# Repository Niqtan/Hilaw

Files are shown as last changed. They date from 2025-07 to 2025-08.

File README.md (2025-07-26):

# Hilaw (3D Printed Instant Camera)

## Project Aims

Hilaw, in english, Raw, is a hybrid analog & digital camera used for taking personal pictures in order to preserve memories. 

Before snapping a picture, a sample image will pop up in the TFT display, having a preview unlike traditional polaroid cameras. Then, using an Arducam module as the camera sensor, it is able to capture images with of high quality.

Afterwards, logic is sent to the thermal printer to print that picture instantly. In the long term, using a thermal printer with sticker paper (I want to be able to stick my memories), will be very cost-effective than traditional film paper, albeit only white and black colors will be in the picture when printing.

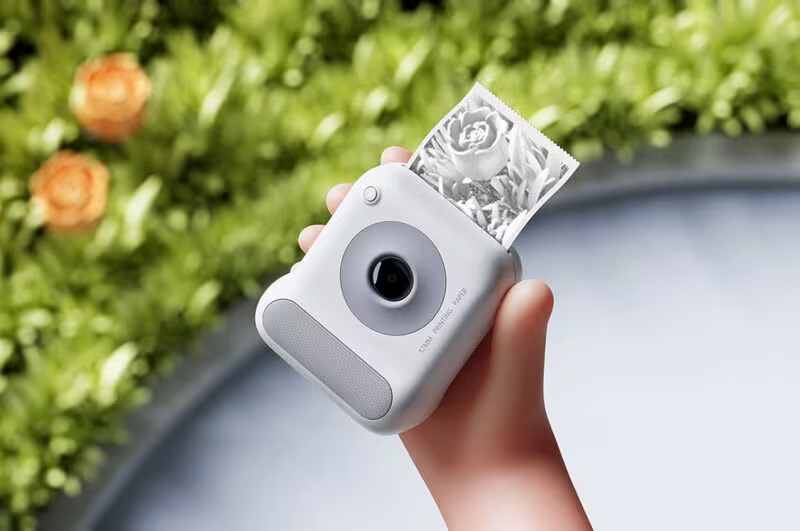
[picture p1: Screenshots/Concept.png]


Image 1. Concept of the project
Courtesy of [TrendHunter](https://www.trendhunter.com/trends/thermal-print-camera)

## Power Management PCB
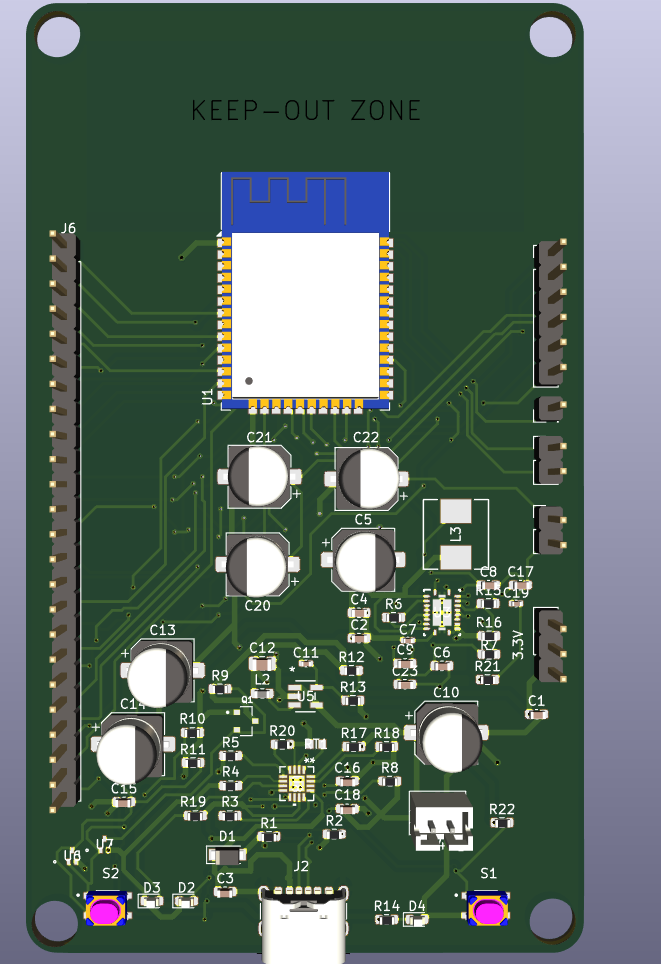
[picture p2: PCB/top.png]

Image 2. Top view of PCB

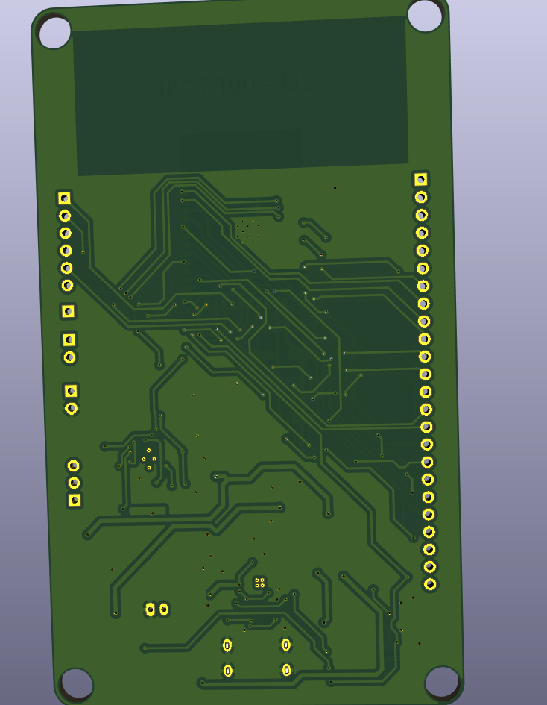
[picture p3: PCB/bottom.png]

Image 3. Bottom view of PCB

## Layout & Schematic
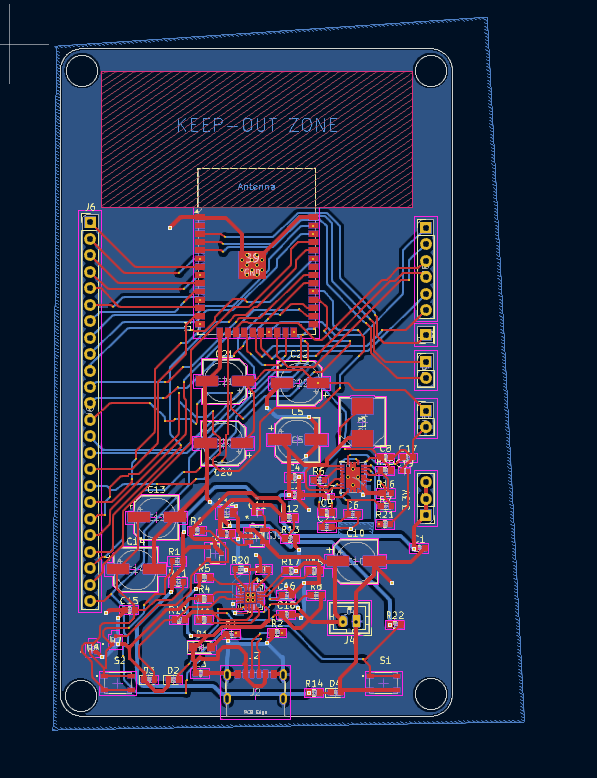
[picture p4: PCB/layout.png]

Image 4. PCB Layout & Connections 

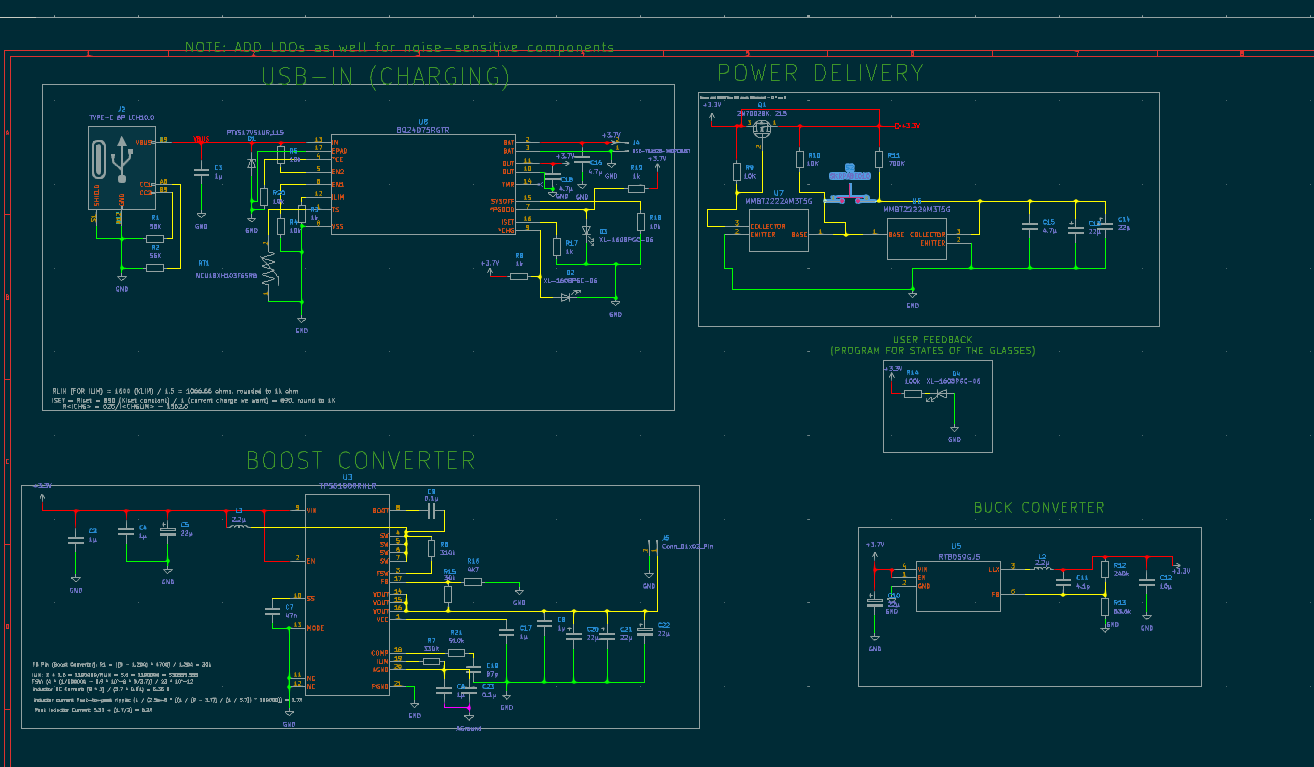
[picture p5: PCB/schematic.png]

Image 5. Power Schematic of the PCB

P.S. The PCB was mainly used for creating a power management module just for this. The rest are pretty much built-in modules to buy.

## CAD
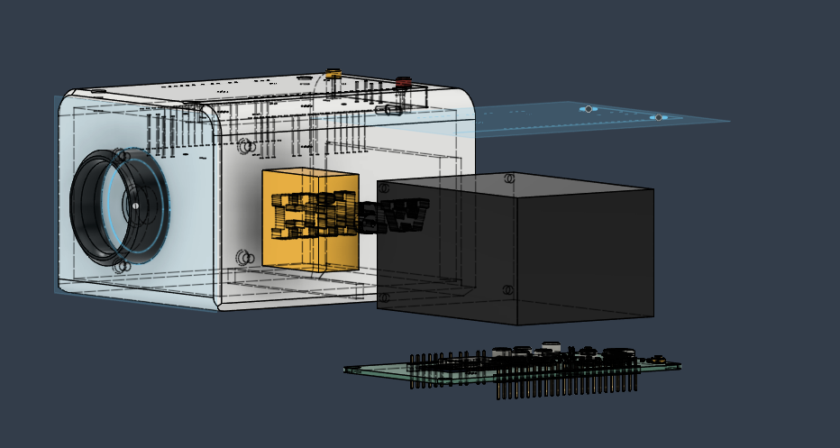
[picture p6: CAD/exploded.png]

Image 6. Exploded View of the CAD

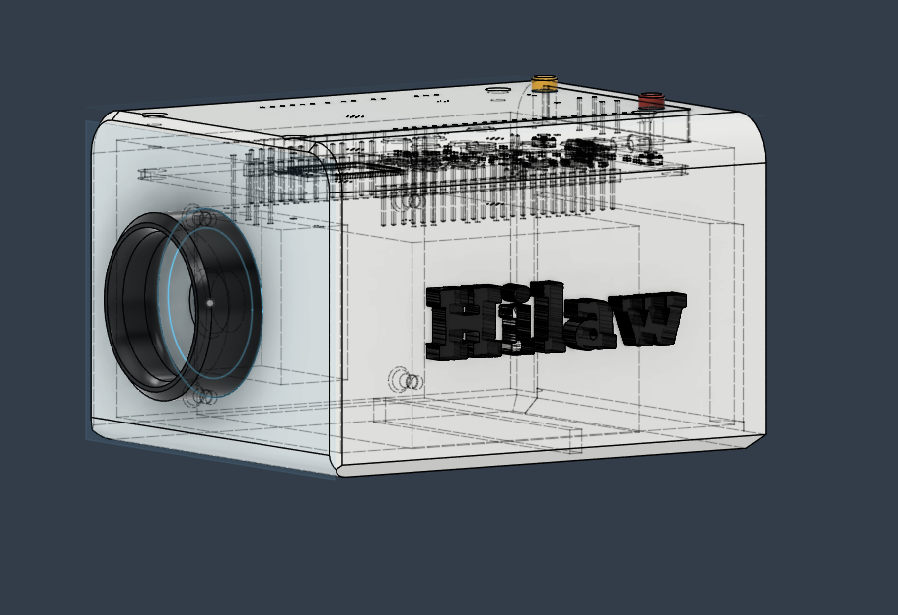
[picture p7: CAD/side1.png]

Image 7. Side View of the CAD

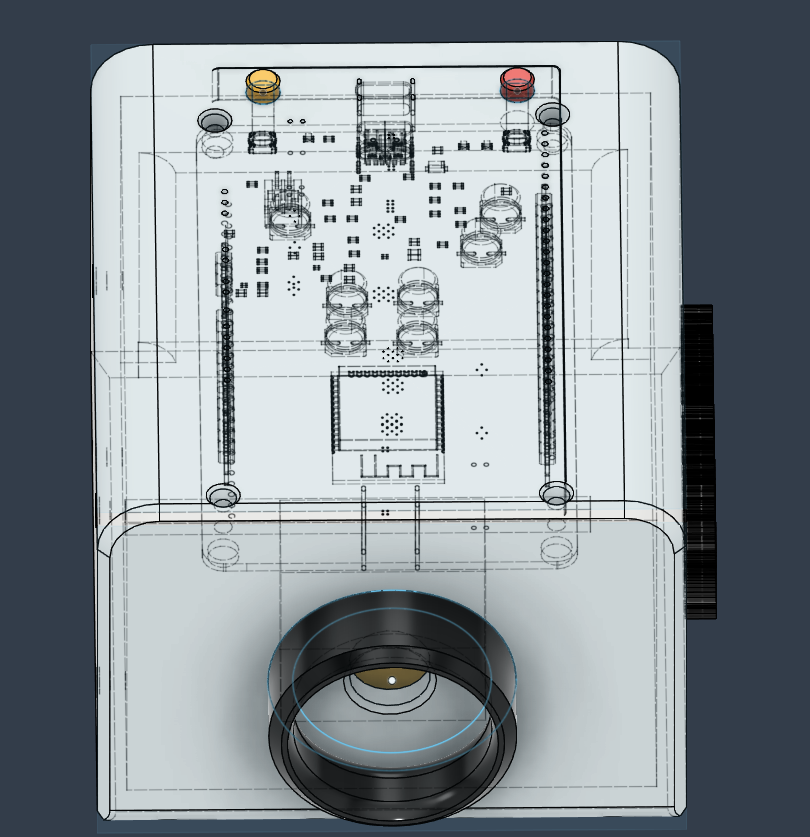
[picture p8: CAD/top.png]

Image 8. Top view of the CAD

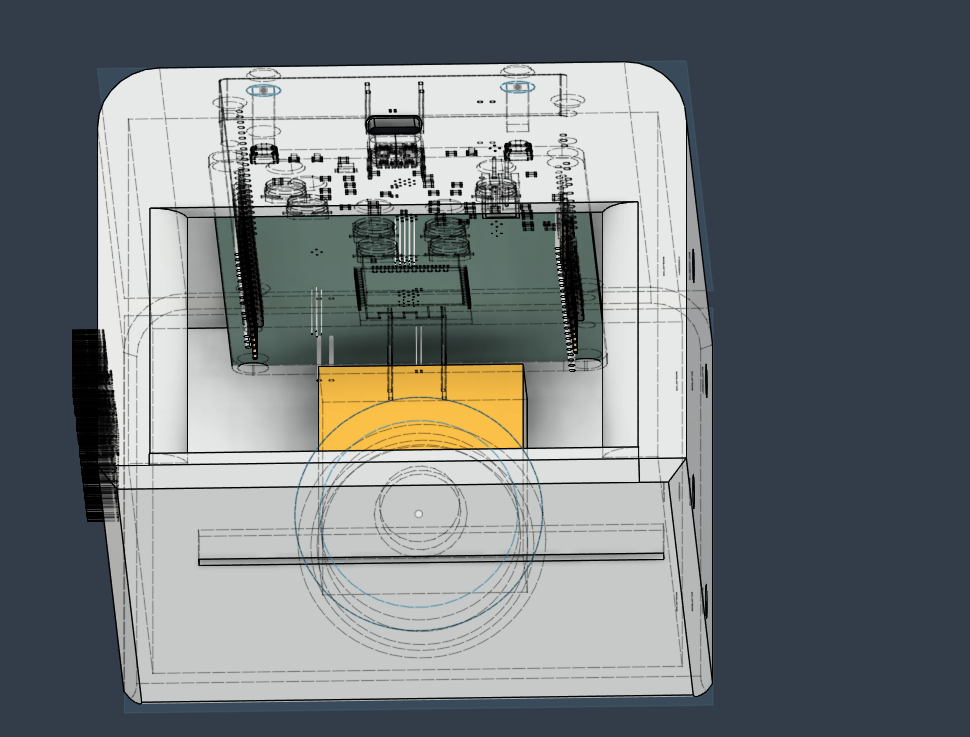
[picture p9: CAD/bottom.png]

Image 9. Bottom View of the CAD

## 3D Printing
In terms of 3D Printing this project, I will print this in Resin since some of these are curved (also the lens cutout is circular). You may print this in Resin with the following parameters:

Layer height: 0.05mm

Orientation: 30-45 degrees

thats pretty much it 

## BOM
[View the bom](BOM.csv)

## Firmware
Have not yet started on the firmware. I am going to choose the Arduino IDE in order to program the ESP32-WROOM-32 since it is much more convenient for prototyping.

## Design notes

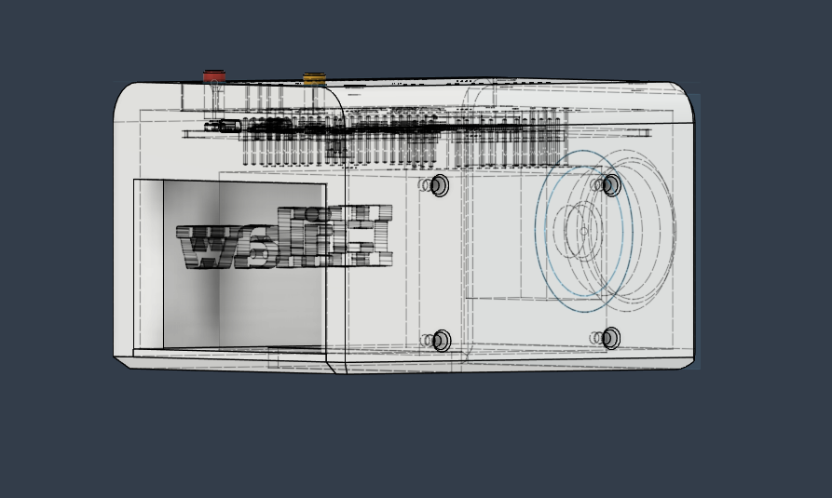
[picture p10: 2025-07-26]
CAD/side2.png

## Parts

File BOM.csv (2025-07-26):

Comment | Designator | Footprint | LCSC Part # | Total (USD)
1µ Unpolarized capacitor | C1,C2,C3,C4,C6,C8,C17 | C_0603_1608Metric | C1592 | IN PCBA
22µ Polarized capacitor | C5,C10,C13,C14,C20,C21,C22 | CP_Elec_6.3x5.4 | C7469954 | IN PCBA
47n Unpolarized capacitor | C7 | C_0402_1005Metric | C1525 | IN PCBA
0.1µ Unpolarized capacitor | C9,C23 | C_0603_1608Metric | C1590 | IN PCBA
4.1p Unpolarized capacitor | C11 | C_0402_1005Metric | C1525 | IN PCBA
10µ Unpolarized capacitor | C12 | C_0805_2012Metric | C1713 | IN PCBA
4.7μ Unpolarized capacitor | C15,C16,C18 | C_0603_1608Metric | C1705 | IN PCBA
87p Unpolarized capacitor | C19 | C_0402_1005Metric | C1525 | IN PCBA
PTVS17VS1UR,115 Zener diode | D1 | Nexperia_CFP3_SOD-123W | C396100 | IN PCBA
XL-1608PGC-06 Light emitting diode | D2,D3,D4 | LED_0603_1608Metric | C7371905 | IN PCBA
USB_C_Receptacle_GCT_USB4125-xx-x-0190_6P_TopMnt_Horizontal | J2 | TYPE-C 6P LCH10.0 USB Power-Only 6P Type-C Receptacle connector | C5187470 | IN PCBA
USE-702528-500PCBJST Generic connector, single row, 01x02, script generated | J4 | JST_PH_B2B-PH-K_1x02_P2.00mm_Vertical | C5251182 | IN PCBA
Conn_01x24_Pin Generic connector, single row, 01x24, script generated | J6 | PinHeader_1x24_P2.54mm_Vertical | C7430380 | IN PCBA
Conn_01x03_Pin Generic connector, single row, 01x03, script generated | J7 | PinHeader_1x03_P2.54mm_Vertical | C49257 | IN PCBA
Conn_01x06_Pin Generic connector, single row, 01x06, script generated | J8 | PinHeader_1x06_P2.54mm_Vertical | C37208 | IN PCBA
Conn_01x01_Pin Generic connector, single row, 01x01, script generated | J10 | PinHeader_1x01_P2.54mm_Vertical | C81276 | IN PCBA
2.2µ Inductor | L2 | L_0603_1608Metric | C1033 | IN PCBA
2.2µ Inductor | L3 | IND_FXL0630_CMT | C167211 | IN PCBA
2N7002BK, 215 0.2A Id, 200V Vds, N-Channel MOSFET, 2.6V Logic Level, TO-92 | Q1 | TRANS_PMV130ENEAR | C458143 | IN PCBA
56K Resistora | R1,R2 | R_0603_1608Metric | C23206 | IN PCBA
1k Resistor | R3,R8,R17,R19 | R_0603_1608Metric | C11702 | IN PCBA
10k Resistor | R4,R5,R18,R20,R22 | R_0603_1608Metric | C25804 | IN PCBA
310k Resistor | R6 | R_0603_1608Metric | C23137 | IN PCBA
330K Resistor | R7 | R_0603_1608Metric | C23137 | IN PCBA
10K Resistor | R9,R10 | R_0603_1608Metric | C25804 | IN PCBA
700K Resistor | R11 | R_0603_1608Metric | C25606 | IN PCBA
240k Resistor | R12 | R_0603_1608Metric | C4197 | IN PCBA
53.6k Resistor | R13 | R_0603_1608Metric | C23074 | IN PCBA
100k Resistor | R14 | R_0603_1608Metric | C25803 | IN PCBA
30k Resistor | R15 | R_0603_1608Metric | C18681 | IN PCBA
4k7 Resistor | R16 | R_0603_1608Metric | C100444 | IN PCBA
910k Resistor | R21 | R_0603_1608Metric | C23263 | IN PCBA
NCU18XH103F6SRB | RT1 | TRES_NCU18XH103F6SRB_MUR | C162670 | IN PCBA
SKRPABE010 | S1,S2 | SW_SKRPABE010 | C115360 | IN PCBA
ESP32-WROOM-32 RF Module, ESP32-D0WDQ6 SoC, Wi-Fi 802.11b/g/n, Bluetooth, BLE, 32-bit, 2.7-3.6V, onboard antenna, SMD | U1 | ESP32-WROOM-32 | C82899 | IN PCBA
TPS61088RHLR | U3 | RHL0020A | C87357 | IN PCBA
RT8059GJ5 | U5 | TSOT-23-5_RIT | C20542 | IN PCBA
MMBT2222AM3T5G | U6,U7 | SOT-723_0P85X1P25_ONS-M | C896289 | IN PCBA
BQ24075RGTR | U8 | RGT16_1P7X1P7 | C15464 | IN PCBA
NOT IN PCB |  |  |  | IN PCBA
ARDUCAM (B0401) | N/A | N/A | N/A | $53.66
GOOJPRT QR204 Thermal Printer | N/A | N/A | N/A | $20.18
TFT_320x240 ( provided) | N/A | N/A | N/A | $0
Shipping & Etc
Aliexpress Thermal Printer |  |  |  | $16.87
PCBA Assembly |  |  |  | $102.55
PCB & PCBA Shipping |  |  |  | $11.72
 |  |  |  | $204.98

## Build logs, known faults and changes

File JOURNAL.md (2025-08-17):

---
title: "Hilaw"
author: "Niq Suguitan"
description: "Holy shit I hate running out of storage ~ probably me" 
created_at: "2025-07-08"
---

| Date started: July 7, 2025

Total hours spent: 57 hours

# Entry #0 - 07-07-25

Research on the components

So for this entry, I've been mainly just going around scouting components
in digikey.

Here are some obsidian notes:

Project Making - Building your own Instax Camera - 07-05-25

Project Name: Hilaw

Features:
- OLED screen preview (Hybrid between digital and analog)
	- Allow users to choose when to print it
- Press a button -> take a pictures
- Adjust settings
- Storage (SD Card)
- Processing on a thermal printer
- Power
	- Latching circuit
	- USB-C w SD CARD

Parts needed:
- ArduCAM
- TFT LCD
- Thermal Printer
- MCU (ESP BOARD SERIES)
	- ESP-32-S3
- Power system

Components - Camera Module - 07-07-25

Characteristics
- Megapixels
	- Megapixels are usually a metric for cropping
	- Basically, if you crop something, it will still retain its quality 

What makes a better image quality?
- Attributed to lower noise
- Better colours
- Dynamic Range

Great camera modules:
- ESP32-CAM

The good thing about ESP32-CAM:
- Cost-effective
- Doesn't take too much dev time
- Fits right perfectly
- Option to be coded with the ESP board series

Cons of ESP32-CAM:
- Video streaming wasnt the best
	- The resolution wasnt the best

Comparing this with the Raspberry Pi Cam V2
- RP
	- Image quality - much better due to SONY sensor
	- 8 MP

Why is the ESP32-CAM stitll much better?
- Its compact and wireless
- Not that complex for this project

For this project, I would pick a camera that is:
- Plug and play, fast *development*
- Has the bare minimum
- Doesn't have to have manual image control

Ends there

Total hours spent: 5 hours

# Entry #1 - 07-19-25 - Researching more components

You guessed it! More research!

What is thermal printing?
- Imagine the receipts, thermal printing is used to print those

By using the same principle of thermal printers, we can:
- Print instantly using heat

Cons of thermal printing
- They start to fade away
- Depends on paper

Thermal Printer vs Inkjet
- Inkjet
	- Paper jam
- Thermal Printers
	- Embedded Thermal Printer V2.0

Components - LCD vs OLED Screen - 07-07-25

Feature focused on: Preview of the camera's printed image

What is OLED?
- Display technology that exhibits amazing contrast since the pixels turn off to display black
- Composed of organic material that emits light when an electric current is applied

LCD
- Utilizes a backlight that shines through liquid crystals to create an image
- Control the amount of light that passes through, dictating the color and brightness of pixels

Benchmarks

Contrast ratio and black levels
- OLED technology outshiens LCD when it comes to this
- Each pixel on the OLED screen is independently lit,

LCD
- On the other hand, LCDs, regardless of backlight technology used, always emit some level of light even when trying to display black, leading a lower contrast ratio

Lifespan and Burn-in
- LCD displays are not susceptible to these issues
- OLED
	- The organic materials in OLED dipslays can degrade over time
	- Moreover, if static images are displayed for extended periosd, OLED screens can suffer from burn-in
		- Where ghost images are permanently imprinted in the screens

Energy Efficiency
- Another area where LCDs tend to excel
	- Generally consume less power than OLEDs when displaying bright or white backgrounds
	- However, the same cannot be said when dark or black images are on the screen as OLEDs consume less power 

Conclusion: 
- We're gonna use a TFT LCD
	- Difference between a TFT LCD and a normal one is that its much more robust (TFT LCD) due to new technology

Total hours spent: 5 hours

# Entry #2 - 07-22-25 - Researching Power Electronics & Doing the Schematic

For this entry, I've started doing the schematic. I only focused on making this a power only PCB, and I focused the most on getting the power part to work so I can work with the PCB straight away.

Here is another peek of my obisdian note for power calculations:

ESP32-WROOM-32 Power Characteristics:
- Power supply voltage -> -0.3V - 3.6V (absolute max)
- Minimum power supply current -> >= 500mAh
- Probably 800mAh to accomodate for the other components

ILI9341 LCD Characteristics (TFT LCD)
- Supply voltage (Logic): 3.3V (Absolute maximum characteristic)
- Around 100mA

ARDUCAM (Camera sensor)
- Supply voltage: 3.3V to 5V
- Peak current (Working): 154mA

Thermal Printer (DF Robot Embedded printer)
- Working voltage: 9V
- Working current: 1.5A - 2A when printing

What to do:
- Since the thermal printer requires a lot more power than the other components, the power system's  requirements would have to be:
	- Battery capacity: 2Ah with discharge rate of 2C 
		  discharge rate is important because it dictates the rate of which it delivers electrical energy
		  That basically means the speed of which it discharges the current we need
		  So lets say we had a 1Ah battery but the charge is only 0.5C, well that would only deliver 500mA

Basic principle of boost converter:
- Boost converters do not boost current, they boost voltage at the expense of current
- Basic principle:
	- V in  * I in = V out * Iout

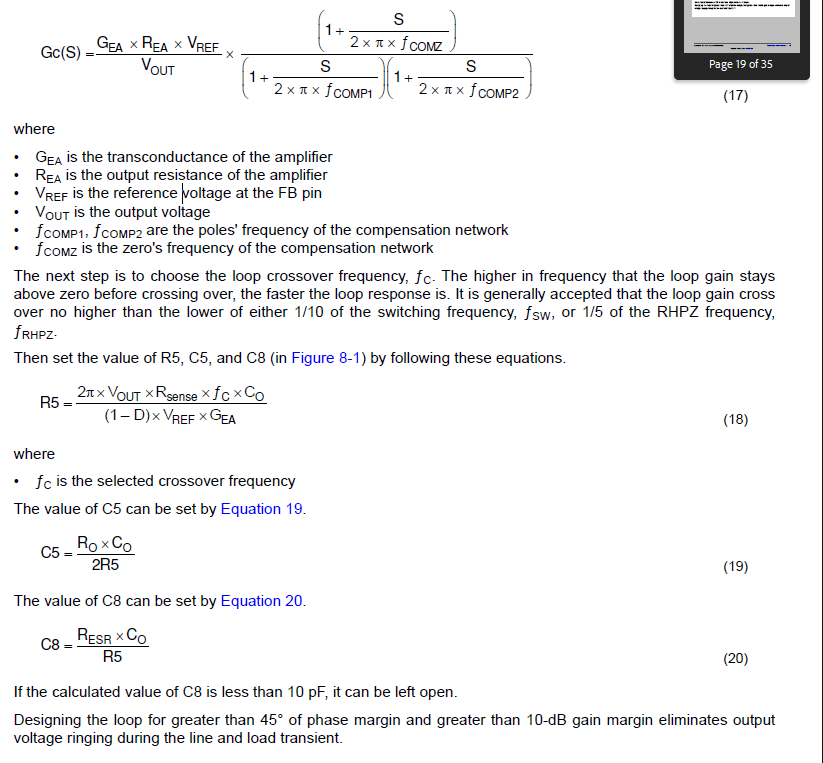
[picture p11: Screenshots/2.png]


Total hours spent: 6 hours

# Entry #4 - 07-24-25 - Finishing up the schematic for power management

In this journal, I mainly polished up the schematic. I've been reading a lot of datasheets and been scrolling thru a lot of them, just to make sure I don't  get anything wrong.

Here's the final schematic (Power management only since this PCB is for that)

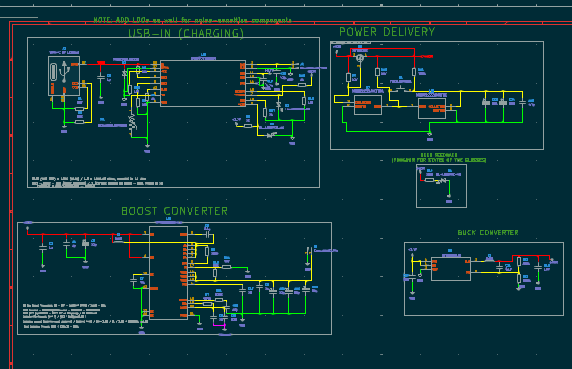
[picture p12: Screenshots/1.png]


Also, I've gotten a jumpstart at the PCB. Its been in the making currently. Didn't get any pictures sadly, forgot em.

Total hours spent: 6 hours

# Entry #5 - 07-25-25 - Finishing the PCB Layout for power management

In this entry, I have finished up the PCB layout. Here is how it looks:

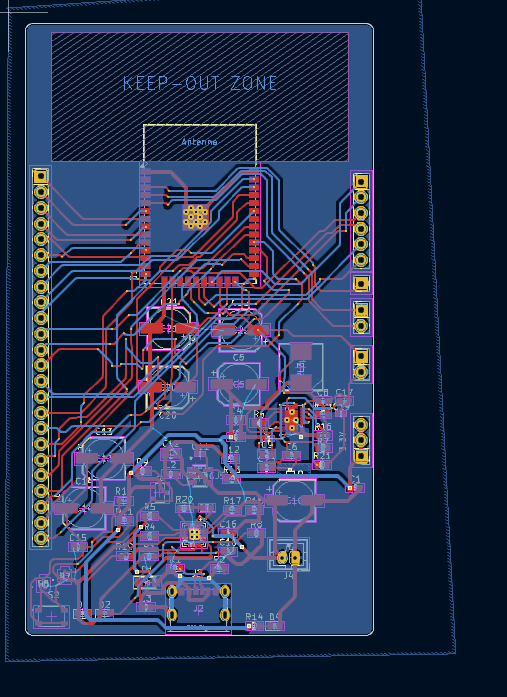
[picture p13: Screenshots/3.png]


Also, I've gotten a jumptart of the CAD. I've been mainly thinking about how to fit all of these components. For example, how would I fit the PCB, thermal printer, and Arducam inside it?

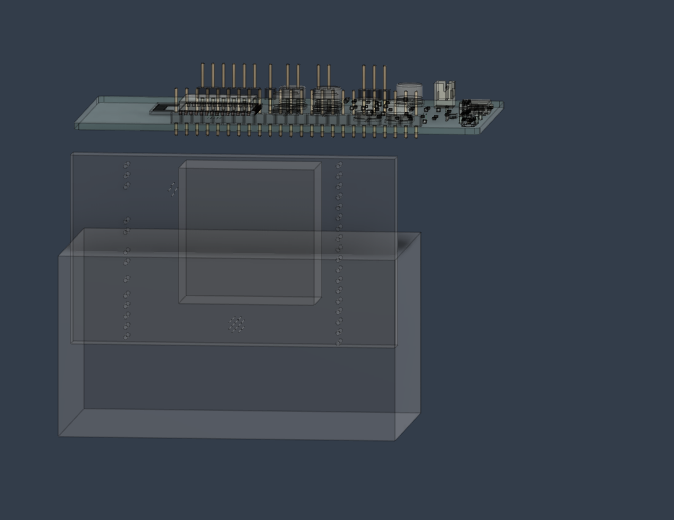
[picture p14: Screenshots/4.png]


Also, I've been brainstorming what the hell do I do with the buttons. I heard its great to have a square on top of the tactile switch with 0.5mm clearance. so I did that on top of the circular model of the button. I did that for both buttons! Power and shutter, which have self-explanatory usages for cameras.

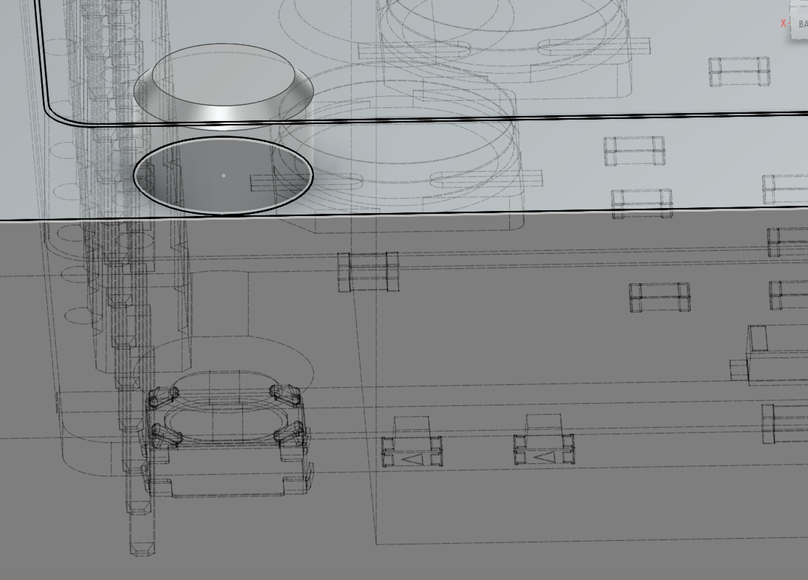
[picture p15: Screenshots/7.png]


Total hours spent: 8 hours

# Entry #6 - 07-26-25 - Finishing up the CAD 

I've been experimenting with how to mount the PCB so that it is stable throughout the usage of the PCB. I decided to go for screws with the standoffs so it doesnt fall on the ceiling of the CAD.

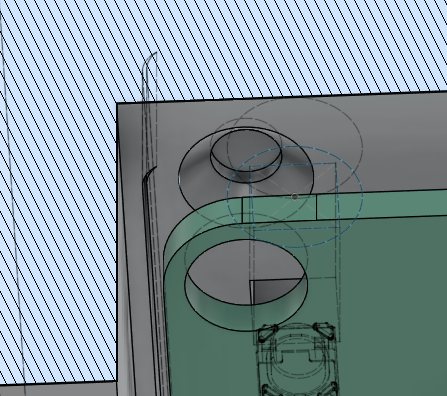
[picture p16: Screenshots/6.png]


Aaaandd... here is what the final CAD looks like! I decided to make this super simple. I didn't want it to be that designy, since I just wanted to use this

Here is what it looks like:


total hours spent: 6 hours

# Entry 7 - 07-29-25 - Ordering PCB & Other Stuff

For this entry, I've ordered most of what I need to assemble this!

- ✔️ PCB
- ✔️ Thermal Printer
- ✔️ Camera (albeit, differnet one since budget didn't reach)

See pictures:
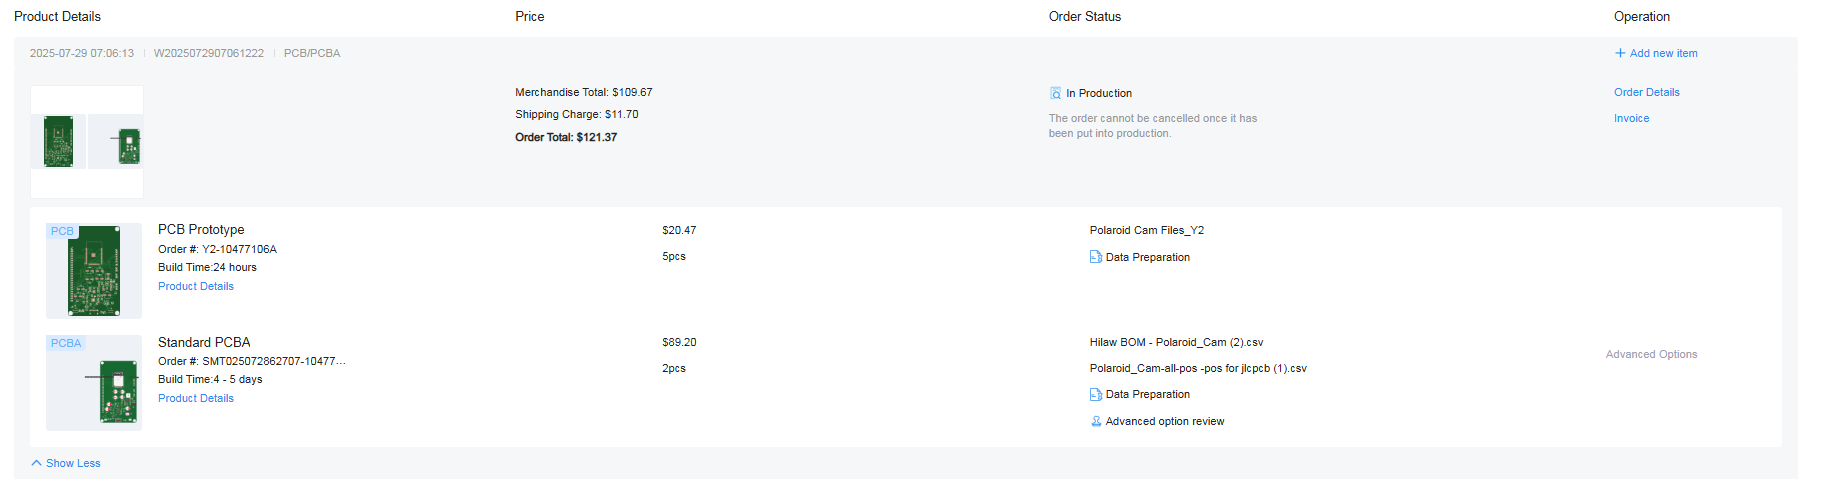
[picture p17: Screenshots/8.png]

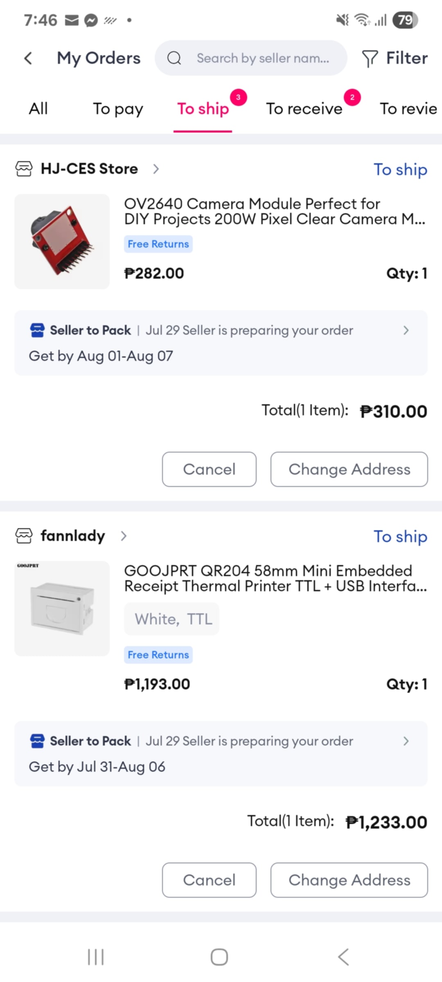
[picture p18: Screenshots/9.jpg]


Total hours spent: 1 hour

# Entry 8 -  07-31-25 - Working with the firmware 

For this entry, I've decided to get a jumpstart on the firmware. 

I mainly got to the initialization part of all components working. For instance, making the camera's initial process work, and the TFT display's display screen to be able to display something.

Besides that, I've also been doing a ton of research on how to make this work, and I think I've got an idea on how to.

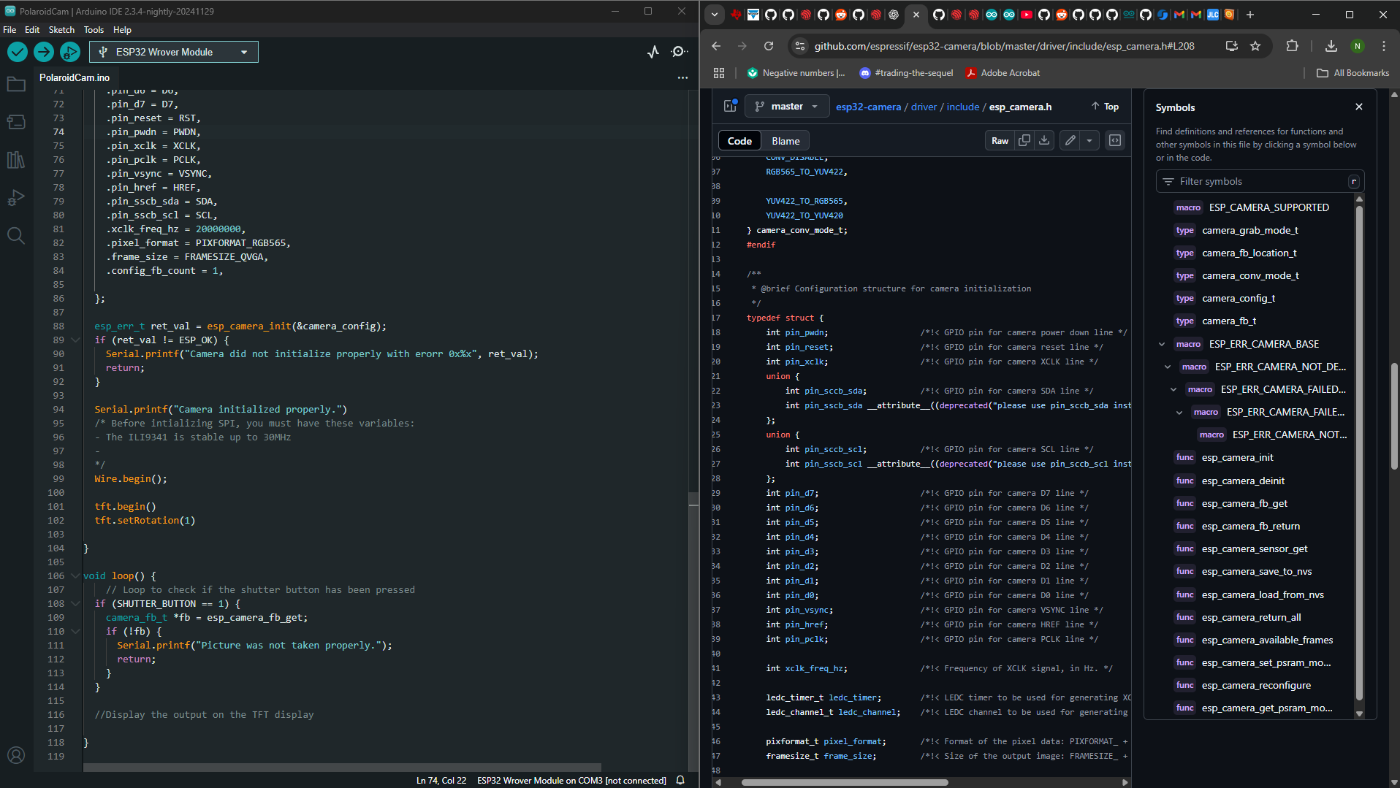
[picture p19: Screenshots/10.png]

Total hours spent: 3 hours

# Entry 9 - 08-01-25 - More Firmware Loading...

Yep! So for this session, I just mainly wanted to work on the firmware.

I specifically worked on polishing the shutter button's logic, and about how to convert the OV2640's logic to a RGB Bit Depth Data for the TFT display to interpret, hence streaming it on the display.

Well, for streaming, it is quite WIP for now. 

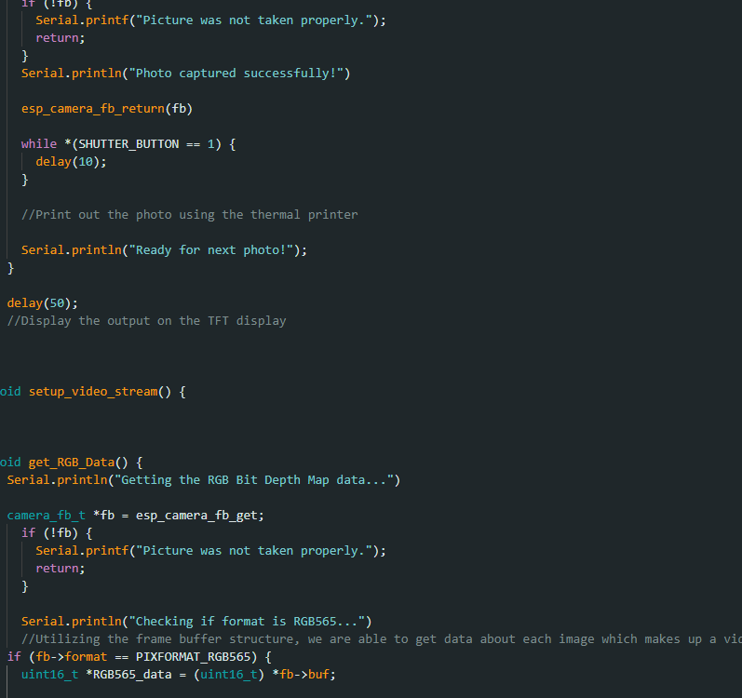
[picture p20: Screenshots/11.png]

Total hours spent: 1 hour

# Entry 10 - 08-10-25 - All stuff arrived & Assembling prototype

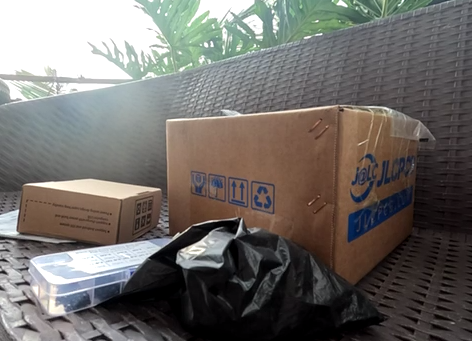
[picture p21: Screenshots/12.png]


Yay! So for this session, the parts have officially arrived (all of em).

So once that happened, I decided to go and assemble the prototype with the right connections. I planned to connect all the connections first with jumper wires first and then we can test out that firmware.
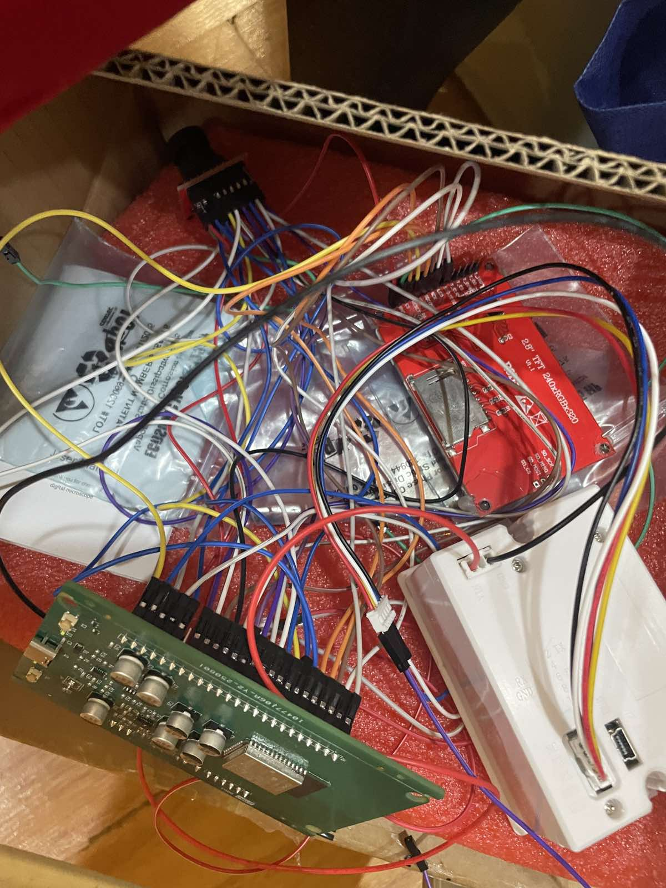
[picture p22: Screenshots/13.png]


Total Hours spent: 2 hours

# Entry 11 - 08-12-25 - Finishing up the PCB assembly and checking connections

Yep! Did some PCB assembly and some checking of connections.

Huh, but for some odd reason, why isn't my battery working? To be exact, when I connect the battery to the JST connector, why do I not get any readings from the pads of the JST connector? 

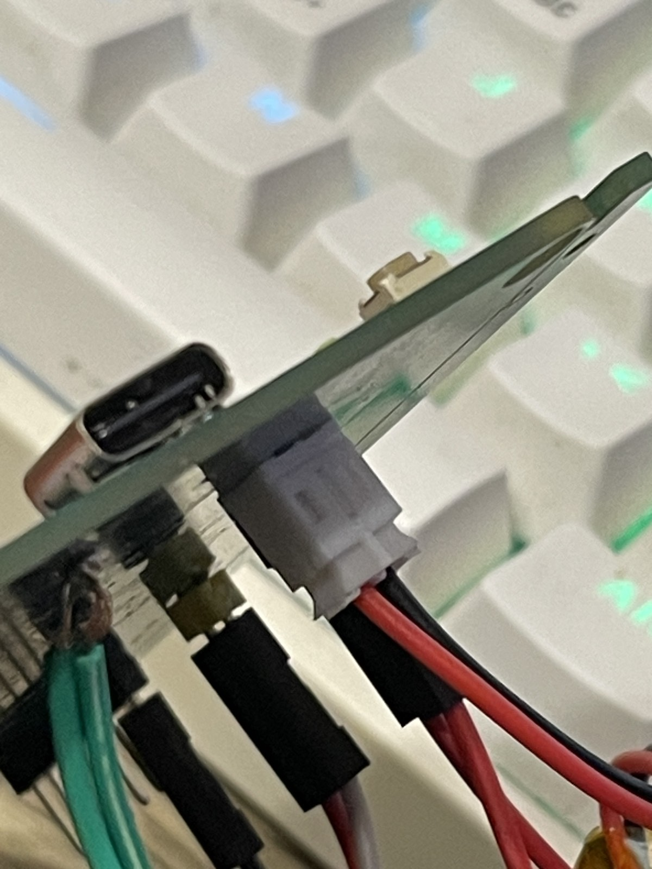
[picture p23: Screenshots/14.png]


Some things I've tried:
- Check if the battery is dead, which is not.
- Check for proper crimping of the connector (yep it is. Otherwise, how would've I be able to probe it inside of the jst connector of the battery.)
- Tested for continuity between the red metal wire of the battery and the PCB pad of where the power source is supposed to go. Still didn't work
- As mentioned in the fourth bullet point, I also tried it for the GND metal wire, same outcome.

I have no idea exactly why this is happening. It should be a simple plug and play yet what I'm experiencing is something very weird and unusual. Perhaps there's something wrong with the orientation? I did tell JLCPCB to assemble the JST connector on the PCB board upside down (180 degrees), which shouldn't change how it should be. The footprint still is exactly how it is on the PCB.

Whatever it is, I'll try to solve it.

Total hours spent: 2 hours

# Entry 12 - 08-13-25 - Finished up the firmware and testing it!

Yep! So for this entry, I've managed to finish the firmware.

Here are the things I've implemented:
- Implemented a video of each frame to display on the TFT display.
- Being able to display that picture at the end
- Implemented and set up the thermal printer
- Converting the RGB565 data into a bitmap for the printer to print
- Polished the initialization part on some stuff

Here's my favorite line of code(s) :D:

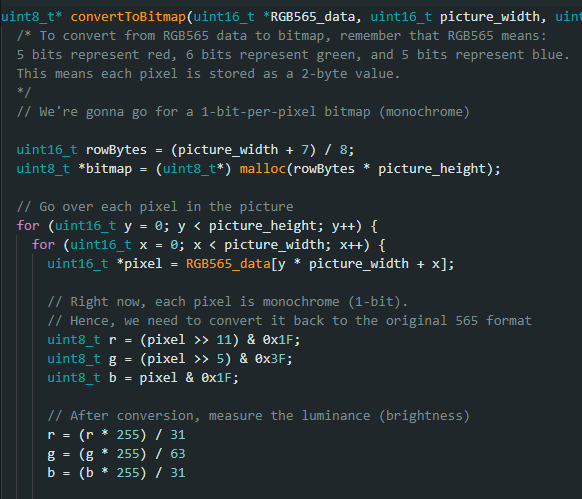
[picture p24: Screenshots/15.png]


Here are also some obsidian notes of the things I've learnt:

What is a RGB Bit Depth Map?
- 2D grayscale images of the same size as the RGB images they are associated with
- The gray level of each pixel of the depth map indicates the distane to the camera of its corresponding RGB Pixel
Turning a RGB Bit Depth Map into a video for the camera
- In order to tur nthe RGB Bit depth map into a video camera, we simply just need to put a while loop to loop through each frame
- Of course, we need to add a delay in order to calculate for a certain FPS so that we may not overwhelm the MCU
Basics of converting RGB565 data to its bitmap version:
- Pixels
	- The atoms of the image, "picture element" which is the smallest dot of an image
	- Each pixel stores color information
	- Ex:
		- RGB565 ->  16 bits per pixel (5 red, 6 green, and 5 blue)
		- Monochrome 1-bit -> 1 bit per pixel
- Bitmap
	- "The map of pixels"
	- A bitmap is an array of pixel data laid out in memory, usually from left to right, top to bottom
	- Each row is a scanline
	- 8 pixels -> 1 byte
So for turning the RGB data into a bitmap version:
- Initialize the bitmap as an array of unsigned 8 bit integers using the dimensions of the picture
- For each x and y bit of that picture, convert the RGB565 data into a monochrome pixel
- Afterwards,   unpack RGB565 into its individual R, G, and B components
- Measure the brightnenss (luminance) of each component
- Use conditionals to set it up for a white or a black pixel by going to each byte and getting each bit's position to manipulate the bits value

Now, moving onto the testing, I found out that the reason why the battery wouldn't provide any power.

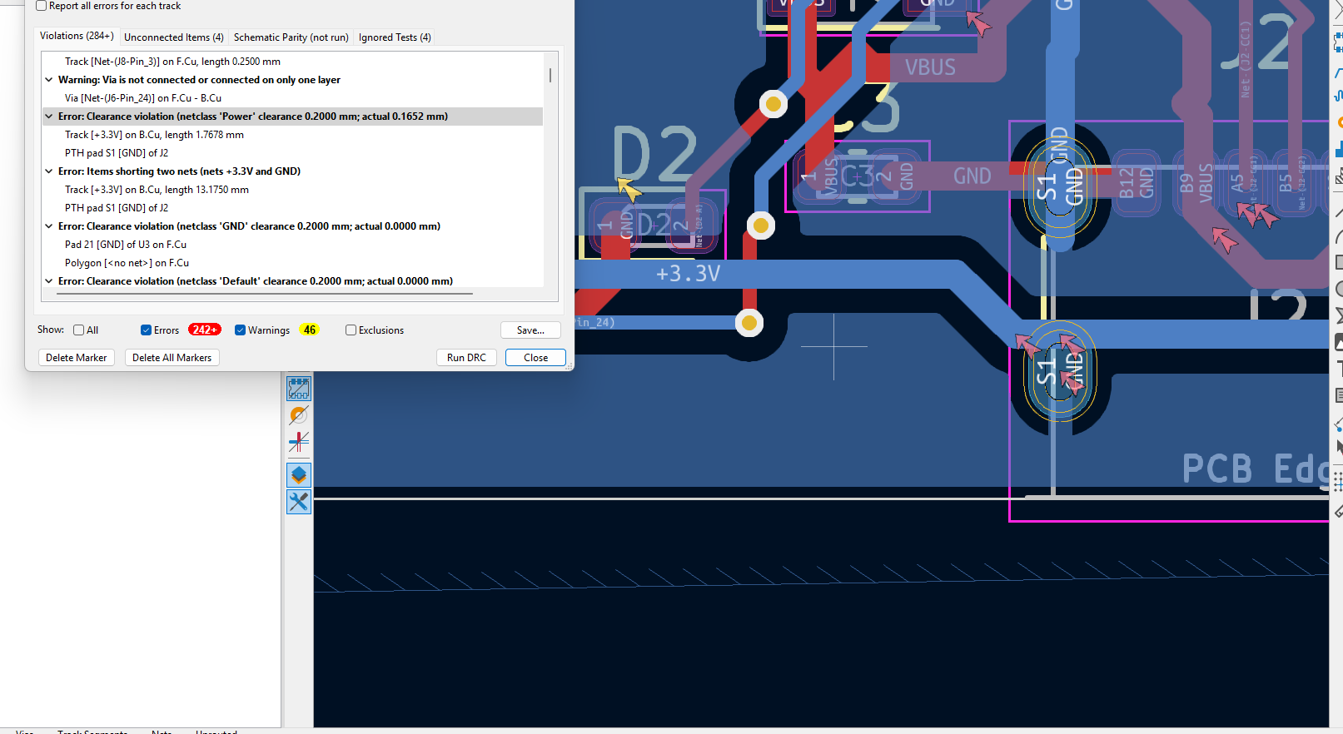
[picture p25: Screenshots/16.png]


I forgot to check DRC and rushed submitting this. Welp, time to cut that trace!

Total hours spent: 5 hours

# Entry 13 - 08-14-25 - Cutting the Trace and finding the short circuits

For this entry, yes, I was able to cut that trace and was able to test continuity just fine.

However, another problem came up.... how come theres still a short circuit between GND and my power rail? I tried searching for it but to no avail.

It's just so hard to honestly pinpoint where the shortcircuit truly happened. There's too many factors to consider.
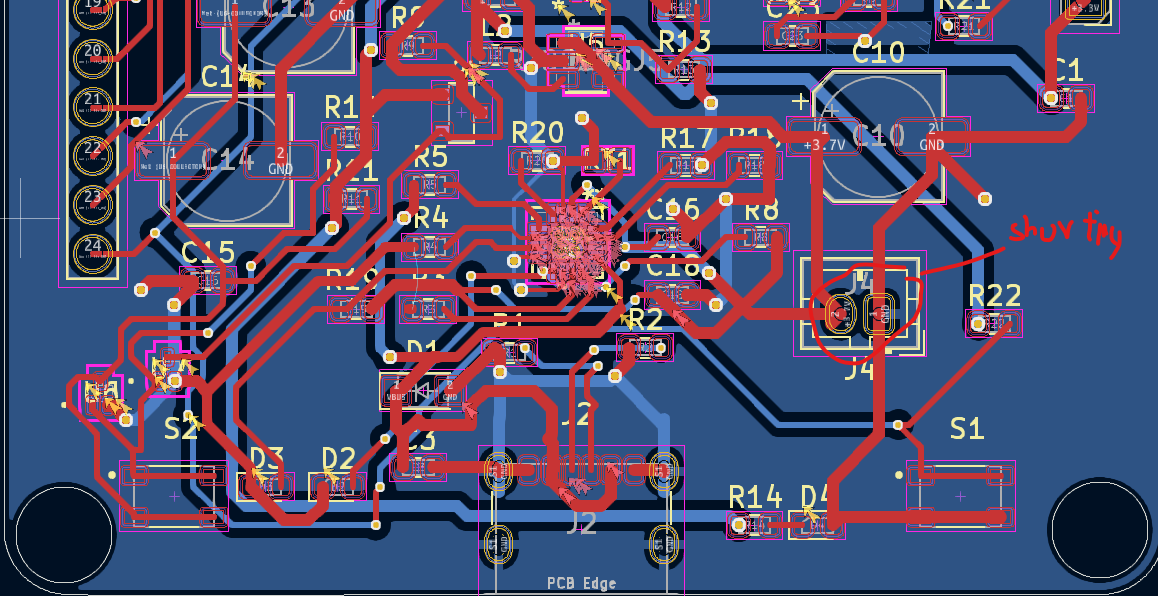
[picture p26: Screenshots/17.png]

Total hours spent: 3 hours
 
 # Entry 13 - 08-16-25 Finding the root source of the short circuit

 So for this entry, I've decided to do something clever. Since I ordered 5 boards, with 2 of them being assembled, I decided to make one of the assembled ones
 into a test board. I was planning like to make the other one into the final thing. Hence, that's what I did.

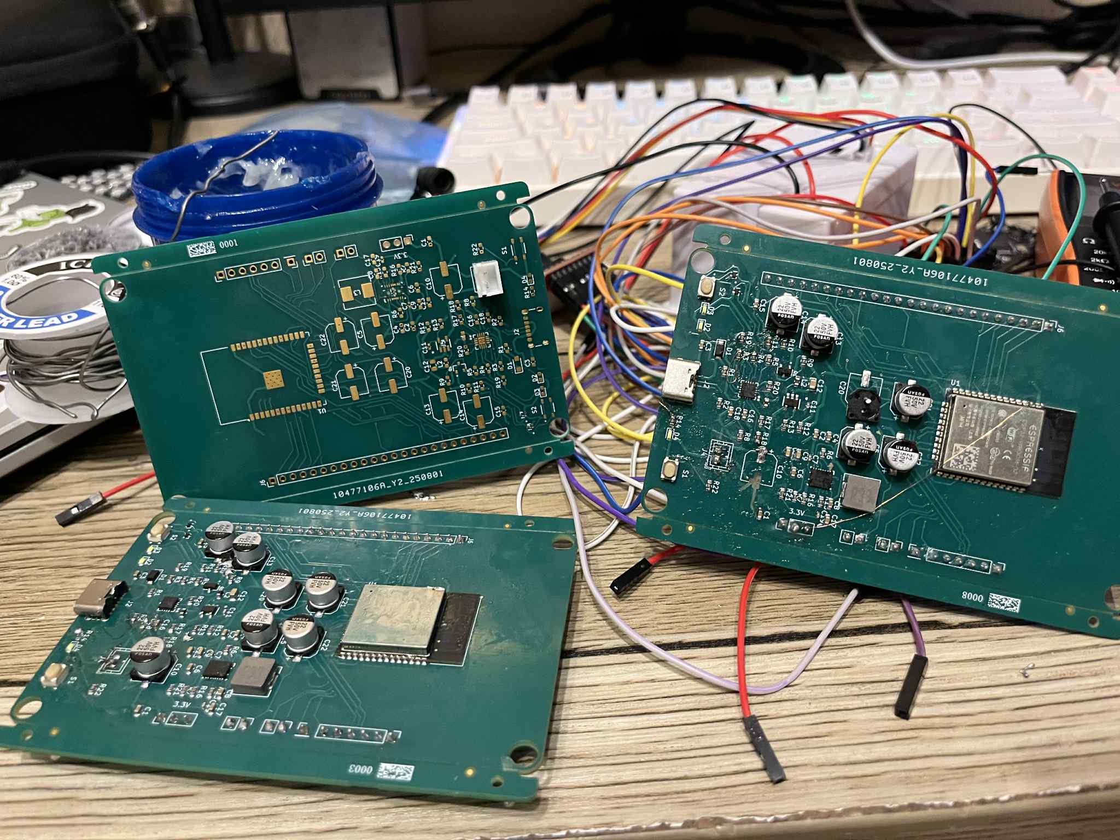
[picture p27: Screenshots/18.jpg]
 

Then, when I did that, I tried looking for the short. From desoldering capacitors, resistors, to even ICs. Eventually, I came to know that the one short circuiting was the battery management IC, BQ24075RGTR. I have no idea why it short circuits in my PCB. But honestly, knowing that It's not that important in my board, I removed it.

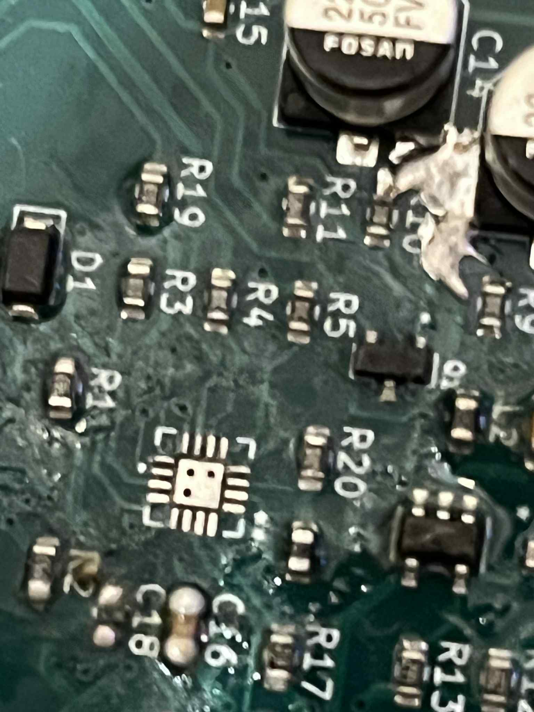
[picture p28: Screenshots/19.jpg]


Boom! It now works! Wow the LED works omg! I'm so excited to make this work ngl. I tried testing the power on different parts of the board, and it seemed fine??

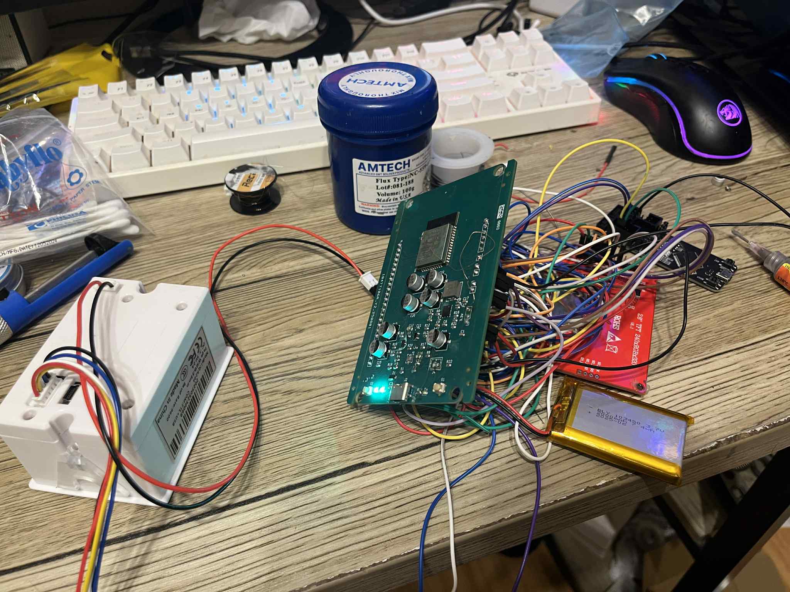
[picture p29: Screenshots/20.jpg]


I'll try flashing the firmware next.

Total hours spent: 3 hours

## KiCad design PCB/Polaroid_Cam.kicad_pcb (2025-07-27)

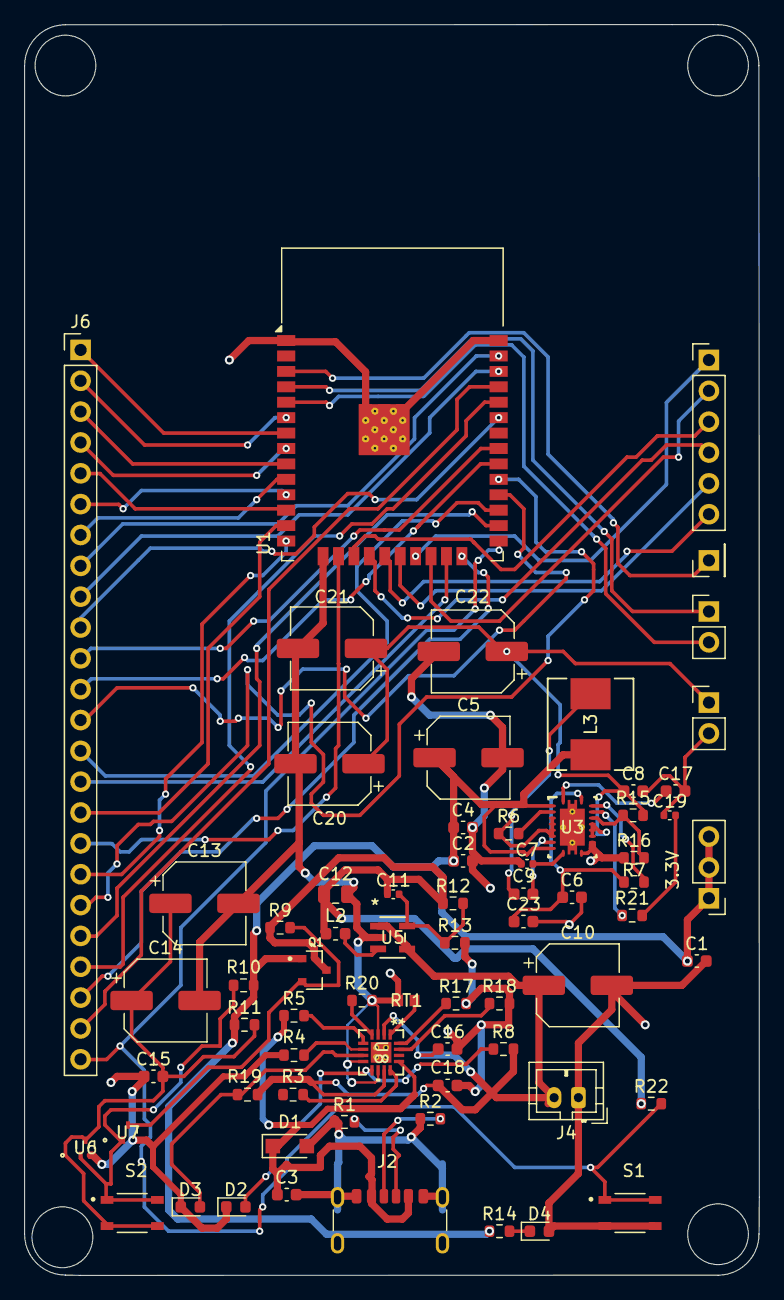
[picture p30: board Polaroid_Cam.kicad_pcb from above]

Board: 2 copper layers, 60.5 x 103.0 mm, 69 parts (0 on the bottom side), 66 nets.

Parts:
C1, C2, C3, C4, C6, C8, C17: 1µ; C_0603_1608Metric
C5, C10, C13, C14, C20, C21, C22: 22µ; CP_Elec_6.3x5.4
C7: 47n; C_0402_1005Metric
C9, C23: 0.1µ; C_0603_1608Metric
C11: 4.1p; C_0402_1005Metric
C12: 10µ; C_0805_2012Metric
C15, C16, C18: 4.7μ; C_0603_1608Metric
C19: 87p; C_0402_1005Metric
D1: PTVS17VS1UR,115; Nexperia_CFP3_SOD-123W
D2, D3, D4: XL-1608PGC-06; LED_0603_1608Metric
J2: TYPE-C 6P LCH10.0; USB_C_Receptacle_GCT_USB4125-xx-x-0190_6P_TopMnt_Horizontal
J4: USE-702528-500PCBJST; JST_PH_B2B-PH-K_1x02_P2.00mm_Vertical
J5, J9: Conn_01x02_Pin; PinHeader_1x02_P2.54mm_Vertical
J6: Conn_01x24_Pin; PinHeader_1x24_P2.54mm_Vertical
J7: Conn_01x03_Pin; PinHeader_1x03_P2.54mm_Vertical
J8: Conn_01x06_Pin; PinHeader_1x06_P2.54mm_Vertical
J10: Conn_01x01_Pin; PinHeader_1x01_P2.54mm_Vertical
L2: 2.2µ; L_0603_1608Metric
L3: 2.2µ; IND_FXL0630_CMT
Q1: 2N7002BK, 215; TRANS_PMV130ENEAR
R1, R2: 56K; R_0603_1608Metric
R3, R8, R17, R19: 1k; R_0603_1608Metric
R4, R5, R18, R20, R22: 10k; R_0603_1608Metric
R6: 310k; R_0603_1608Metric
R7: 330K; R_0603_1608Metric
R9, R10: 10K; R_0603_1608Metric
R11: 700K; R_0603_1608Metric
R12: 240k; R_0603_1608Metric
R13: 53.6k; R_0603_1608Metric
R14: 100k; R_0603_1608Metric
R15: 30k; R_0603_1608Metric
R16: 4k7; R_0603_1608Metric
R21: 910k; R_0603_1608Metric
RT1: NCU18XH103F6SRB; TRES_NCU18XH103F6SRB_MUR
S1, S2: SKRPABE010; SW_SKRPABE010
U1: ESP32-WROOM-32
U3: TPS61088RHLR; RHL0020A
U5: RT8059GJ5; TSOT-23-5_RIT
U6, U7: MMBT2222AM3T5G; SOT-723_0P85X1P25_ONS-M
U8: BQ24075RGTR; RGT16_1P7X1P7

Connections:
+3.3V: C1.1, C2.1, C4.1, C5.1, C11.1, C12.1, J7.1, J7.2, J7.3, L2.2, L3.1, Q1.1 (S), Q1.3 (D), R9.1, R10.1, R11.1, R12.1, R14.1, R22.1, U3.2 (EN), U3.9 (VIN)
+3.7V: C10.1, C16.1, C18.1, J4.2, R8.2, R19.1, U5.1 (EN), U5.4 (VIN), U8.2 (BAT), U8.11 (OUT)
/Power Sheet/VBUS: C3.1, D1.1 (K), J2.A9 (VBUS), J2.B9 (VBUS), R5.1, U8.13 (IN)
AGround: C6.2, C23.2
GND: C1.2, C2.2, C3.2, C4.2, C5.2, C7.1, C8.2, C10.2, C12.2, C13.2, C14.2, C15.1, C16.2, C17.2, C18.2, C19.1, C20.2, C21.2, C22.2, D1.2 (A), D2.1 (K), D3.1 (K), D4.2 (A), J2.A12 (GND), J2.B12 (GND), J2.S1 (SHIELD), J4.1, J5.2, R1.1, R2.1, R3.2, R4.2, R13.2, R16.1, R17.2, R18.2, R20.2, RT1.1, S1.3, S1.4, U1.1 (GND), U1.15 (GND), U1.38 (GND), U1.39 (GND), U3.11 (NC), U3.12 (NC), U3.13 (MODE), U3.21 (PGND), U5.2 (GND), U6.2 (EMITTER), U7.2 (EMITTER), U8.3 (BAT), U8.8 (VSS), U8.10 (OUT), U8.17 (EPAD)
unnamed: C9.2, L3.2, R6.1, U3.4 (SW), U3.5 (SW), U3.6 (SW), U3.7 (SW)
unnamed: C19.2, R21.2
unnamed: D2.2 (A), R8.1, U8.9 (*CHG)
unnamed: D3.2 (A), R19.2, U8.7 (*PGOOD)
unnamed: D4.1 (K), R14.2
unnamed: J2.A5 (CC1), R2.2
unnamed: J2.B5 (CC2), R1.2
unnamed: C8.1, C20.1, C21.1, C22.1, J5.1, R15.2, U3.14 (VOUT), U3.15 (VOUT), U3.16 (VOUT)
unnamed: J6.1, U1.7 (IO35)
unnamed: J6.2, U1.6 (IO34)
unnamed: J6.3, U1.9 (IO33)
unnamed: J6.4, U1.8 (IO32)
unnamed: J6.5, U1.12 (IO27)
unnamed: J6.6, U1.11 (IO26)
unnamed: J6.7, U1.10 (IO25)
unnamed: J6.8, U1.37 (IO23)
unnamed: J6.9, U1.36 (IO22)
unnamed: J6.10, U1.33 (IO21)
unnamed: J6.11, U1.31 (IO19)
unnamed: J6.12, U1.30 (IO18)
unnamed: J6.13, U1.28 (IO17)
unnamed: J6.14, U1.27 (IO16)
unnamed: J6.15, U1.23 (IO15)
unnamed: J6.16, U1.13 (IO14)
unnamed: J6.17, U1.16 (IO13)
unnamed: J6.18, U1.14 (IO12)
unnamed: J6.19, U1.29 (IO5)
unnamed: J6.20, U1.26 (IO4)
unnamed: J6.21, U1.34 (RXD0/IO3)
unnamed: J6.22, U1.24 (IO2)
unnamed: J6.23, U1.35 (TXD0/IO1)
unnamed: J6.24, R22.2, S1.1, S1.2, U1.25 (IO0)
unnamed: J8.1, U1.21 (SDO/SD0)
unnamed: J8.2, U1.22 (SDI/SD1)
unnamed: J8.3, U1.17 (SHD/SD2)
unnamed: J8.4, U1.18 (SWP/SD3)
unnamed: J8.5, U1.20 (SCK/CLK)
unnamed: J8.6, U1.19 (SCS/CMD)
unnamed: J9.1, U1.4 (SENSOR_VP)
unnamed: J9.2, U1.5 (SENSOR_VN)
unnamed: J10.1, U1.3 (EN)
unnamed: Q1.2 (G), R9.2, U7.3 (COLLECTOR)
unnamed: C6.1, C23.1, R7.2, U3.20 (AGND)
unnamed: C9.1, U3.8 (BOOT)
unnamed: R21.1, U3.18 (COMP)
unnamed: R15.1, R16.2, U3.17 (FB)
unnamed: R6.2, U3.3 (FSW)
unnamed: R7.1, U3.19 (ILIM)
unnamed: C7.2, U3.10 (SS)
unnamed: C17.1, U3.1 (VCC)
unnamed: C11.2, R12.2, R13.1, U5.5 (FB)
unnamed: L2.1, U5.3 (LLX)
unnamed: R10.2, S2.1, S2.2, U6.1 (BASE), U7.1 (BASE)
unnamed: C13.1, C14.1, C15.2, R11.2, S2.3, S2.4, U6.3 (COLLECTOR)
unnamed: R20.1, U8.4 (*CE)
unnamed: R4.1, U8.6 (EN1)
unnamed: R5.2, U8.5 (EN2)
unnamed: R3.1, U8.12 (ILIM)
unnamed: R17.1, U8.16 (ISET)
unnamed: R18.1, U8.15 (SYSOFF)
unnamed: RT1.2, U8.1 (TS)

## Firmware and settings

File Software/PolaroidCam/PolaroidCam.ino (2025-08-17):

// Libraries

#include <SPI.h>
#include <Wire.h>

//TFT Display

#include <Adafruit_GFX.h>
#include <Adafruit_ILI9341.h>

//Camera
#include "esp_camera.h"

// Thermal Printing

#include "TPrinter.h"
#include <HardwareSerial.h>


/*
**********************
*****Define GPIOs*****
**********************
*/



//MCU Pins

#define SHUTTER_BUTTON 0

// Camera (I2C)

#define SCL 22 
#define SDA 21
#define PWDN 18

#define PCLK 19
#define CAM_RST 23
#define D0 36
#define D1 13
#define D2 39
#define D3 12
#define D4 15
#define D5 4
#define D6 14
#define D7 2


//Thermal Printer (TTL) (Serial number 2)
#define RX 25
#define TX 26

// TFT Display (SPI)
#define MISO 17
#define MOSI 33
#define SCK 16
#define CS 27
#define DC 32
#define TFT_RST 5

// Input Only pins
#define VSYNC 35
#define HREF 34

const int printerBaudrate = 9600;
const int SPIMAXFREQ = 3000000;
const uint16_t display_width = 240;
const uint16_t display_height = 320;

uint16_t *RGB565_data = NULL;
uint8_t *bitmap = NULL;

HardwareSerial printerSerial(2);
Tprinter myPrinter(&printerSerial, printerBaudrate);

Adafruit_ILI9341 tft = Adafruit_ILI9341(CS, DC, TFT_RST);

camera_fb_t* renderImage;

void setup() {
  //Initialize all communication protocols here
  micros();
  Wire.begin();
  SPI.begin();
  Serial.begin(115200);

  //Reset the camera first
  pinMode(CAM_RST, OUTPUT);
  digitalWrite(CAM_RST, HIGH);

  // Reset TFT as well
  pinMode(TFT_RST, OUTPUT);
  digitalWrite(TFT_RST, HIGH);
  
  //Configure the camera settings
  camera_config_t camera_config = {
    .pin_d0 = D0,
    .pin_d1 = D1,
    .pin_d2 = D2,
    .pin_d3 = D3,
    .pin_d4 = D4,
    .pin_d5 = D5,
    .pin_d6 = D6,
    .pin_d7 = D7,
    .pin_reset = CAM_RST,
    .pin_pwdn = PWDN,
    .pin_xclk = -1,
    .pin_pclk = PCLK,
    .pin_vsync = VSYNC,
    .pin_href = HREF,
    .pin_sscb_sda = SDA,
    .pin_sscb_scl = SCL,
    .xclk_freq_hz = 0,                                                                                                   
    .pixel_format = PIXFORMAT_RGB565,
    .frame_size = FRAMESIZE_QVGA,
    .jpeg_quality = 12,
    .fb_count = 1

  };
  
  //Initialize the camera using the settings 
  esp_err_t ret_val = esp_camera_init(&camera_config);
  if (ret_val != ESP_OK) {
    Serial.printf("Camera did not initialize properly with error 0x%x", ret_val);
    return;
  }

  Serial.printf("Camera initialized properly.");

  //Begin communication with the TFT
  tft.begin();
  tft.setRotation(1);
  tft.fillScreen(ILI9341_BLACK);

  printerSerial.begin(printerBaudrate, SERIAL_8N1, RX, TX);
  myPrinter.begin();

  //Button
  pinMode(SHUTTER_BUTTON, INPUT);
}

void loop() {
  //Display the current RGB depth map in order to preview the photo
  camera_fb_t *final_fb = NULL;
  final_fb = stream_video();
  
  // Loop to check if the shutter button has been pressed
  if (digitalRead(SHUTTER_BUTTON) == 1) {
    Serial.println("Shutter button pressed!");
    Serial.println("Taking a picture...");

    while (digitalRead(SHUTTER_BUTTON) == 1) {
      delay(10);
    }
    
    renderImage(final_fb);
    Serial.println("Photo captured successfully!");

    //Print out the photo using the thermal printer

    uint16_t picture_width = 384; // 384 pixels per line
    uint16_t picture_height = 288; // Makes it so that it looks shart wiuthout being huge 

    bitmap = convertToBitmap(RGB565_data, picture_width, picture_height);
    printer.printBitmap(bitmap, picture_width, picture_height, 1, true);
    Serial.println("Photo printed!");
    delay(100);

    free(bitmap);
    esp_camera_fb_return(final_fb);
    Serial.println("Ready for next photo!");
  }

  delay(50);
  
}

uint8_t* convertToBitmap(uint16_t *RGB565_data, uint16_t picture_width, uint16_t picture_height) {
  /* To convert from RGB565 data to bitmap, remember that RGB565 means: 
  5 bits represent red, 6 bits represent green, and 5 bits represent blue.
  This means each pixel is stored as a 2-byte value.
  */
  // We're gonna go for a 1-bit-per-pixel bitmap (monochrome)

  uint16_t rowBytes = (picture_width + 7) / 8;
  uint8_t *bitmap = (uint8_t*) malloc(rowBytes * picture_height); 

  // Go over each pixel in the picture
  for (uint16_t y = 0; y < picture_height; y++) {
    for (uint16_t x = 0; x < picture_width; x++) {
      uint16_t pixel = RGB565_data[y * picture_width + x];

      // Right now, each pixel is monochrome (1-bit). 
      // Hence, we need to convert it back to the original 565 format
      uint8_t r = (pixel >> 11) & 0x1F;
      uint8_t g = (pixel >> 5) & 0x3F;
      uint8_t b = pixel & 0x1F;

      // After conversion, measure the luminance (brightness)
      r = (r * 255) / 31;
      g = (g * 255) / 63;
      b = (b * 255) / 31;

      uint8_t brightness = (r * 30 + g * 59 + b * 11) / 100;
      
      uint16_t byteIndex = y * rowBytes + (x / 8);
      uint8_t bitIndex = 7 -  (x % 8);

      // black
      if (brightness < 128) {
        bitmap[byteIndex] |= (1 << bitIndex);
      }

      // white
      else {
        bitmap[byteIndex] &= ~(1 << bitIndex) ;
      }
    }
  }

  return bitmap;
}

camera_fb_t renderImage(camera_fb_t *fb) {

  uint16_t w = fb->width;
  uint16_t h = fb->height;

  //Calculate center image
  uint16_t x = (display_width - w) / 2 
  uint16_t y = (display_height - h) / 2

  Serial.println("Displaying the image...");
  tft.drawRGBBitmap(x, y, RGB565_data, w, h)

  Serial.println("Do u like it?");

  delay(2000);

  return fb;
}

// Function for converting the current format to a RGB Bit Depth Map for the TFT Display
camera_fb_t* stream_video() {
  Serial.println("Getting the RGB Bit Depth Map data...");

  camera_fb_t *last_fb = NULL;

  while (digitalRead(SHUTTER_BUTTON) == 0) {
  
   camera_fb_t *fb = esp_camera_fb_get();
    if (!fb) {
      Serial.printf("Picture was not taken properly.");
      return;
  }

  uint16_t w = fb->width;
  uint16_t h = fb->height;

  //Calculate center image
  uint16_t x = (display_width - w) / 2 
  uint16_t y = (display_height - h) / 2
  
  Serial.println("Checking if format is RGB565...")
    //Utilizing the frame buffer structure, we are able to get data about each image which makes up a video
  if (fb->format == PIXFORMAT_RGB565) {
    RGB565_data = (uint16_t *) fb->buf;

    Serial.print("Image is in RGB565 format!");
    
    //Displaying the image
    tft.drawRGBBitmap(x, y, RGB565_data, w, h)
  }
  else {
    Serial.println("Image is not in RGB565 format")

    // Reconfigure the camera

    sensor_t *reconfigure = esp_camera_sensor_get();
    if (reconfigure) {
      reconfigure->set_pixformat(reconfigure, PIXFORMAT_RGB565);
      Seiral.println("Reconfigured to a RGB565 format!");
    }

    Serial.println("Skipping the current frame for now. Will be RGB565 next frame!");
  }

  //Keep getting a new frame
  esp_camera_fb_return(fb);
  delay(33); //~30 FPS
  
  }
  
  //If button pressed, return.
  final_fb = esp_camera_fb_get();
  return final_fb;

}

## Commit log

2025-07-26 journal and BOM
2025-07-26 polished stuff
    [BOM.csv]
2025-07-26 updated BOM
    [BOM.csv]
2025-07-27 update files
    [Polaroid_Cam.kicad_pcb, Polaroid_Cam.kicad_sch]
